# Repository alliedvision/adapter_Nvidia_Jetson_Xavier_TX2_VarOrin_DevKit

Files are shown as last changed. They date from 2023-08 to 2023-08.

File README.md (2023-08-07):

# Allied Vision CSI-2 Adapter Board for NVIDIA Jetson AGX Orin Xavier TX2 Dev Kit

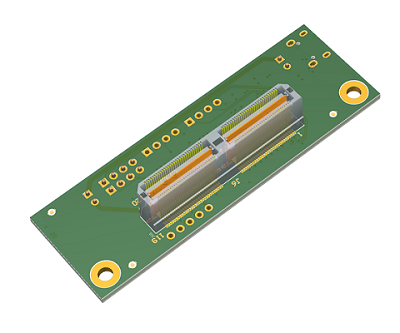
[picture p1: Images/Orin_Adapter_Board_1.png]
Orin_Adapter_Board_1

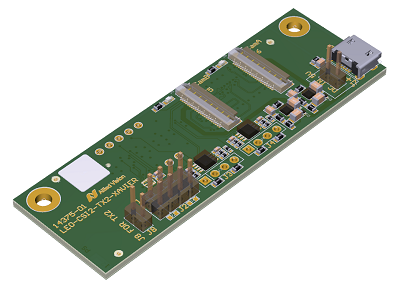
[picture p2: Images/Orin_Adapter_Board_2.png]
Orin_Adapter_Board_2


This repository contains open hardware design files for an adapter board supporting the Allied Vision Alvium CSI-2 camera pinout to NVIDIA's
AGX Orin Developer Kit. The board allows the user to interface with two Alvium MIPI CSI-2 compatible cameras over a Flexible Flat Cable (FFC) connector.

This adapter is similar to the 
[Adapter Board for Nvidia Jetson TX2 Xavier Dev Kit](https://github.com/alliedvision/adapter_Nvidia_Jetson_TX2_Xavier_DevKit), but with a higher connector optimized for the AGX Orin Developer Kit and with minor changes of the default I/O configuration.

AGX Xavier and TX2 Developer Kits are also supported.

You can also purchase the adapter from [Allied Vision](https://www.alliedvision.com/en/products/accessories/interface-connections/#!?cameraInterfacefilter=10) or from our [distributors](https://www.alliedvision.com/en/avt-locations/avt-distributors/).

## Getting Started

These instructions will get you a copy of the design files to make your own adapter boards for development and testing purposes. 
The board can be produced and assembled using the provided design files. Please take a look at the mechanical layers for more information regarding the PCB stackup recommended for fabrication. 

More information is available on our website:

* [User Guide (PDF)](https://cdn.alliedvision.com/fileadmin/content/documents/products/accessories/embedded/user-guide/Jetson-AGX-Orin-Xavier_TX2_Adapter_User-Guide.pdf)
* [Accessories webpage](https://www.alliedvision.com/en/products/accessories/interface-connections/#!?cameraInterfacefilter=10) 
* [Accessories download webpage](https://www.alliedvision.com/en/support/accessory-documentation/)
* [Alvium CSI-2 download webpage](https://www.alliedvision.com/en/support/technical-documentation/alvium-csi-2-documentation/) 

### Prerequisites

* A running installation of Altium.
* A PCB producer & PCBA manufacturer or some soldering skills.
* One of the supported embedded boards:
	* NVIDIA Jetson AGX Orin Developer Kit
  * NVIDIA Jetson AGX Xavier Developer Kit
  * NVIDIA Jetson TX2 Developer Kit 	

* One or two supported MIPI CSI-2 FPC cables, Allied Vision product codes
 18947, 12316, 12317, 12318 
* [One or two Allied Vision Alvium CSI-2 cameras](https://www.alliedvision.com/en/products/embedded-vision-cameras.html)

### Installing

Open the *CSI2-TX2-XAVIER_Rev02.PrjPcb* project file in your Altium environment.

## Built With

[Altium Designer 22](https://www.altium.com/altium-designer/de)
 
## License

This project is licensed under the MIT License - see the [LICENSE](LICENSE) file for details

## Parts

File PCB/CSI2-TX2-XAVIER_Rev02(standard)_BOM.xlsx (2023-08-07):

 | Bill of Materials | CSI2-TX2-XAVIER_Rev02
 | Project : | CSI2-TX2-XAVIER
 | PCBA : |  | Revision : | 02
 | PCB : |  | Revision : | 02
 | Variant : | standard
 | Schematic : | CSI2-TX2-XAVIER_Rev02 | Schematic.pdf
 | Placement : | CSI2-TX2-XAVIER_Rev02 | Overlay.pdf
 | Report Date : | 07.07.2023 | 13:21
 | Alternative Parts :
Quantity | Designator | Comment | Footprint | Description | Manufacturer | Manufacturer Part Number | KHK Part Number
4 | C1, C2, C3, C5 | 100n | C-0402_0.55 | Capacitor Ceramic SMD/0402/16V/X7R/10% | several | several | K8340114
2 | C4, C6 | 100p | C-0402_0.55 | Capacitor Ceramic SMD/0402/50V/X7R/10% | several | several | K8340145
2 | C7, C10 | 100n | C-0603_1.0 | Capacitor Ceramic SMD/0603/50V/X7R/10% | several | several | K8340023
4 | C8, C9, C11, C12 | 10u | C-0805_1.4 | Capacitor Ceramic SMD/0805/16V/X5R/10% | several | several | K8340151
1 | C13 | NL | C-0603_1.0 | Capacitor Ceramic SMD/0603/50V/X7R/10% | several | several
2 | D1, D2 | GREEN | D-0603-LED | Chip LED green 430mcd | Würth | 150060GS75000 | 8172
2 | D3, D4 | ESD9B5.0ST5G | D-SOD923 | DIODE TVS; 400W; 5.8-7.8V; BIDIRECT | ON Semiconductor | ESD9B5.0ST5G | 7250
4 | J1, J2, J3, J4 | NL | CON 1x4 RM2.54 | Stiftleiste; 1x4; 2.54mm; gerade | Harwin | M20-999 0445
2 | J5, J6 | CON FFC22_Inverted | J-FH55-22S-0.5SH - Inverted Pins | FFC Connector 0.5mm shielded | Hirose | FH55-22S-0.5SH | 10357
1 | J7 | NL | CON 1x2 RM2.54 | Stiftleiste; 1x2; 2.54mm; gerade | fischer elektronik | SL 11 124 2 G
1 | J8 | CON1x2 | CON 1x2 RM2.54 | Stiftleiste; 1x2; 2.54mm; gerade | fischer elektronik | SL 11 124 2 G | K7600582
1 | J9 | USB 2.0 Typ B 90° | J-629105150521 | Micro USB 2.0 Typ B 90° | WE | 629 105 150 521 | 14360
1 | J10 | QTH-060-01-L-D-A | J-QTH-060-XX-X-D-A | 120pin B2B Header 0.5 pitch 4.27mm Height | SamTec | QTH-060-01-L-D-A | 10657
1 | LA1 | LABEL 7x7mm | PCB LABEL 7x7 | LABEL 7x7mm | several | several
6 | MRK1, MRK2, MRK3, MRK4, MRK5, MRK6 | Marker Single Layer | PCB_Marker_Pad_top | Position Marker for PCBs
1 | PCB1 | 14375-01 |  | PCB ML04 | several | 14375-01 | 14375-01
4 | R1, R2, R3, R4 | NL | R-0603_0.6 | Standard Resistor SMD/0603/1%/100mW/TK200 | several | several
8 | R5, R6, R10, R11, R13, R14, R17, R18 | 2k0 | R-0402_0.4 | Standard Resistor SMD/0402/1%/63mW/TK100 | several | several | K8250311
4 | R7, R8, R15, R16 | 0R0 | R-0603_0.6 | Standard Resistor SMD/0603/1%/100mW/TK100 | several | several | K8250041
2 | R9, R20 | 3k3 | R-0603_0.6 | Standard Resistor SMD/0603/1%/100mW/TK100 | several | several | K8250070
2 | R12, R19 | 200k | R-0402_0.4 | Standard Resistor SMD/0402/1%/63mW/TK100 | several | several | K8250280
2 | R21, R24 | NL | R-0603_0.6 | Standard Resistor SMD/0603/1%/100mW/TK200
2 | R22, R25 | 270k | R-0603_0.6 | Standard Resistor SMD/0603/1%/100mW/TK100 | several | several | K8250170
2 | R23, R26 | 51k | R-0603_0.6 | Standard Resistor SMD/0603/1%/100mW/TK100 | several | several | K8250156
1 | R27 | 0R0 | R-0603_0.6 | Standard Resistor SMD/0603/1%/100mW/TK200 | several | several | K8250041
1 | U1 | NTB0104GU12,115 | IC-XQFN12_1.7x2x0.5 | IC/LOGIC/Levelshifter;Auto-Dir;Bidirectional;Push-Pull;-40-+125°C/ | NXP | NTB0104GU12,115 | 14383
2 | U2, U3 | PCA9306DCTR | IC-TSSOP8_3.15x4.25x1.3 | IC/LOGIC/LEVELSHIFTER;I2C;AUTO-DIR;1V2-5V/SSOP-8/4.25x3.15x1.3mm | TI | PCA9306DCTR | 9555
2 | U4, U5 | TPS25200DRVT | IC-DFN06_2.0x2.0x0.8 | IC/PWR/LOADSW;2V5-6V5;2A5;0R099/6-WDFN/2x2x0.8mm | Texas Instruments | TPS25200DRVT | 14277

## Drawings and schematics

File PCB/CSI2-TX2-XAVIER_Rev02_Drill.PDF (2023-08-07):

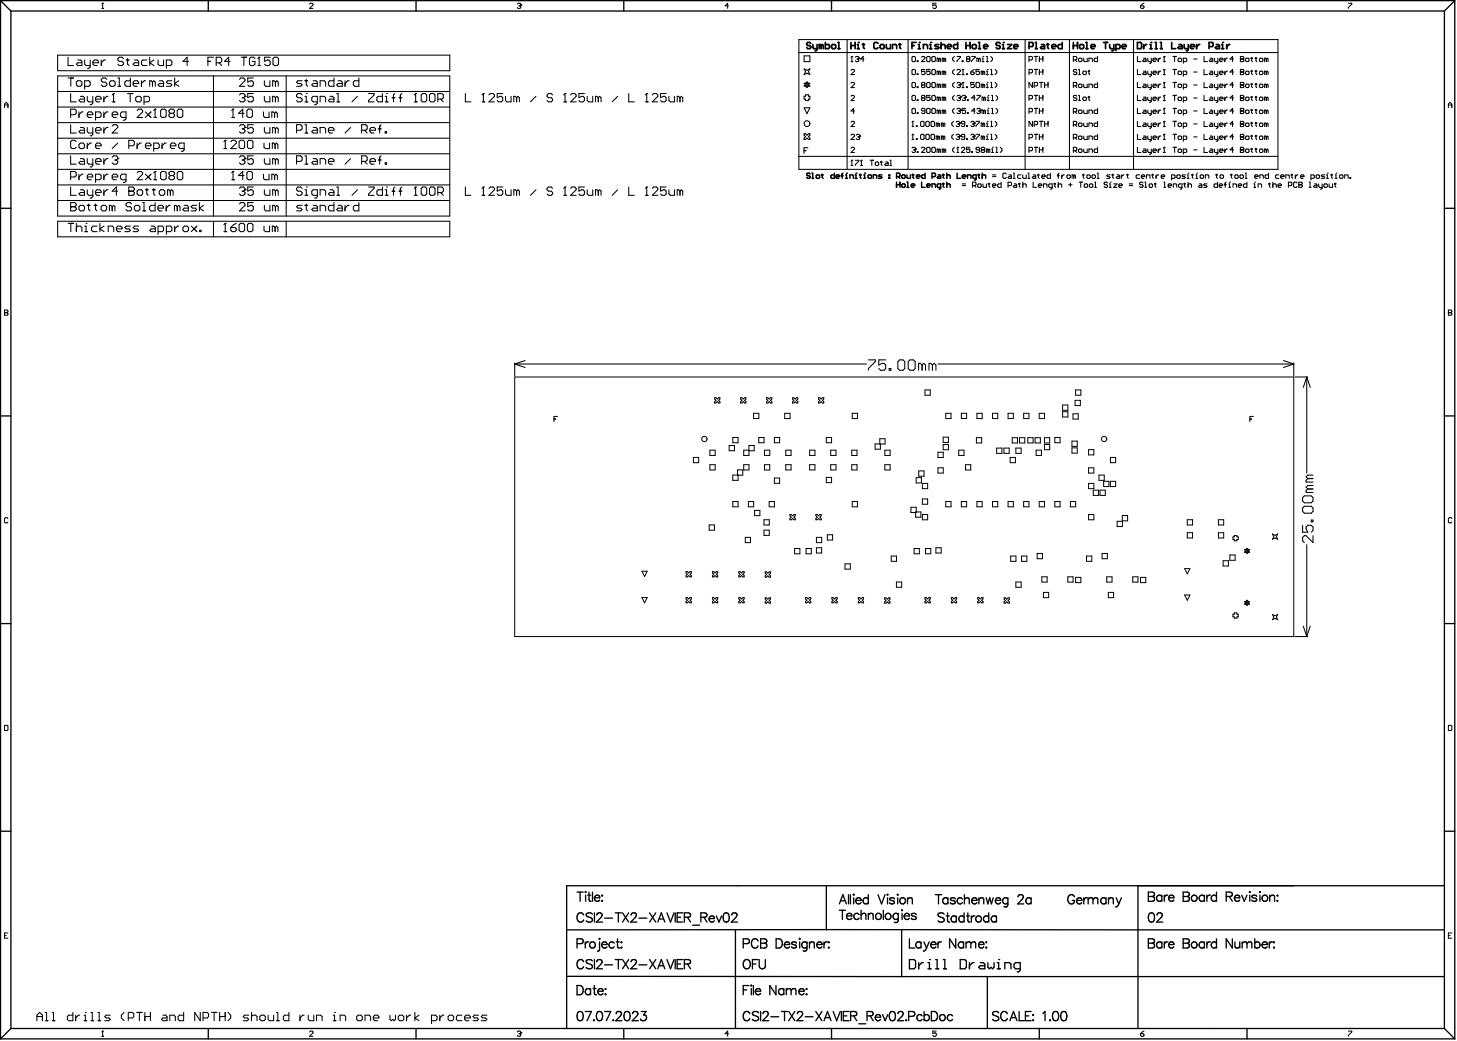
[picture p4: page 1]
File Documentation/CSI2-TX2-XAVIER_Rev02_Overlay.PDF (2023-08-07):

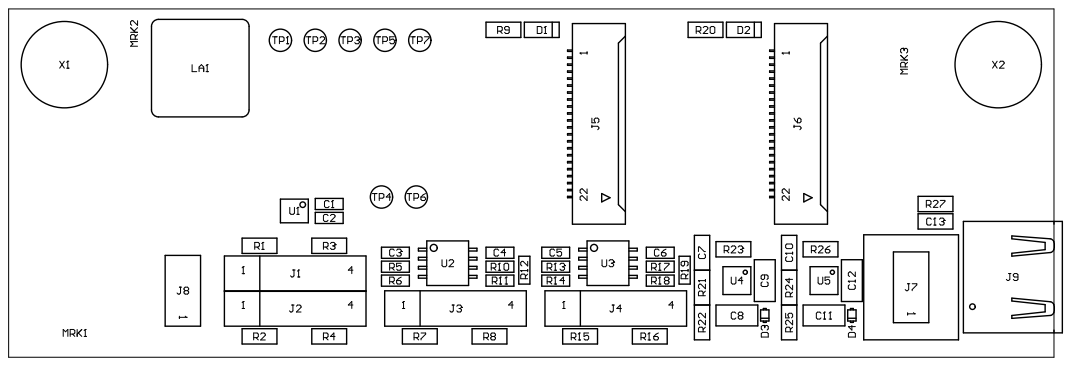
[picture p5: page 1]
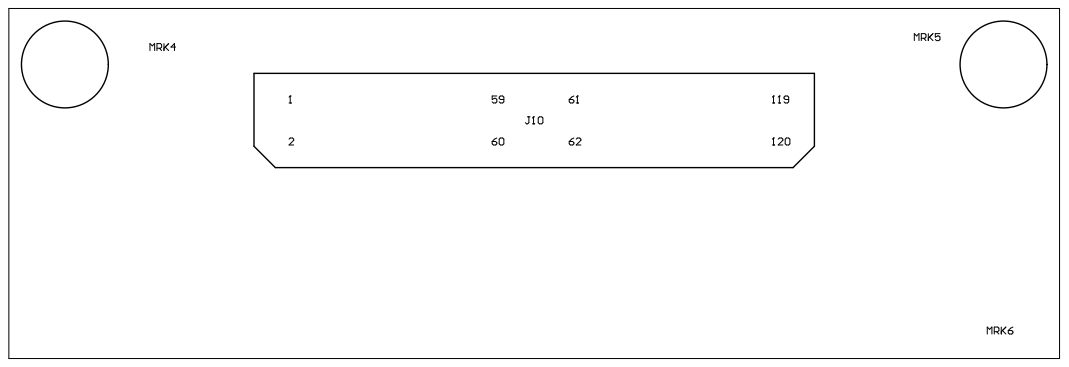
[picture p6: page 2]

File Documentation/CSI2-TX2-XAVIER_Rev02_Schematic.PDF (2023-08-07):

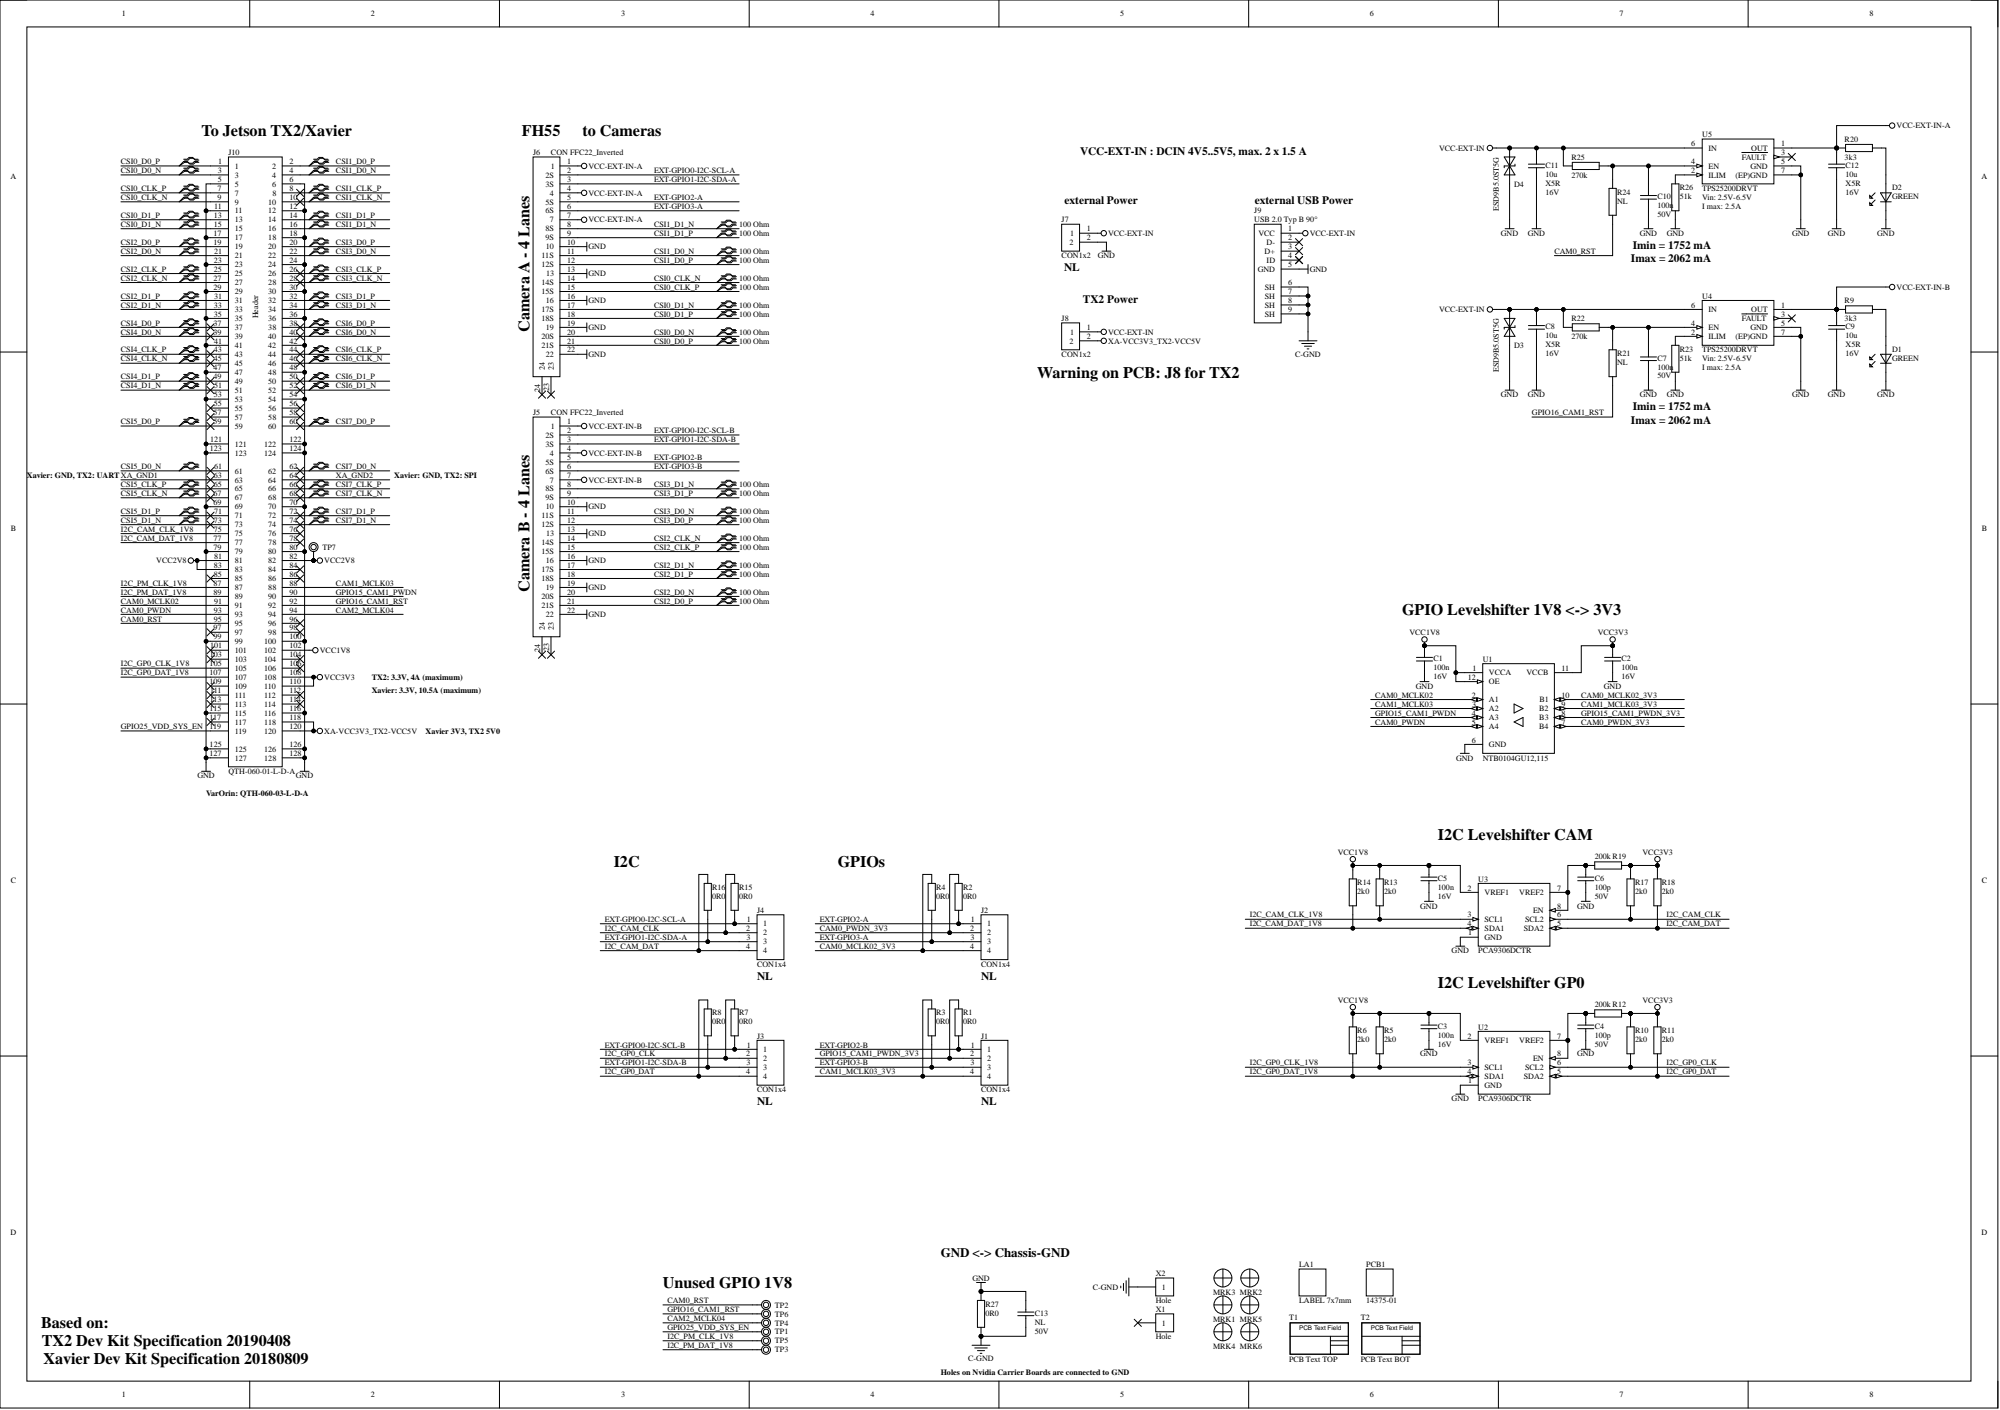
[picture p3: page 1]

VCC-EXT-IN : DCIN 4V5..5V5, max. 2 x 1.5

Camera A - 4 Lanes Camera B - 4 Lanes

GND <-> Chassis-GND GND

Based on:
TX2 Dev Kit Specification 20190408
Xavier Dev Kit Specification 20180809

Holes on Nvidia Carrier Boards are connected to GND
